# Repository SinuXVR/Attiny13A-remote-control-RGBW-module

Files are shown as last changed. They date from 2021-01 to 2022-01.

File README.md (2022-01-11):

# Attiny13A based remote control RGB module

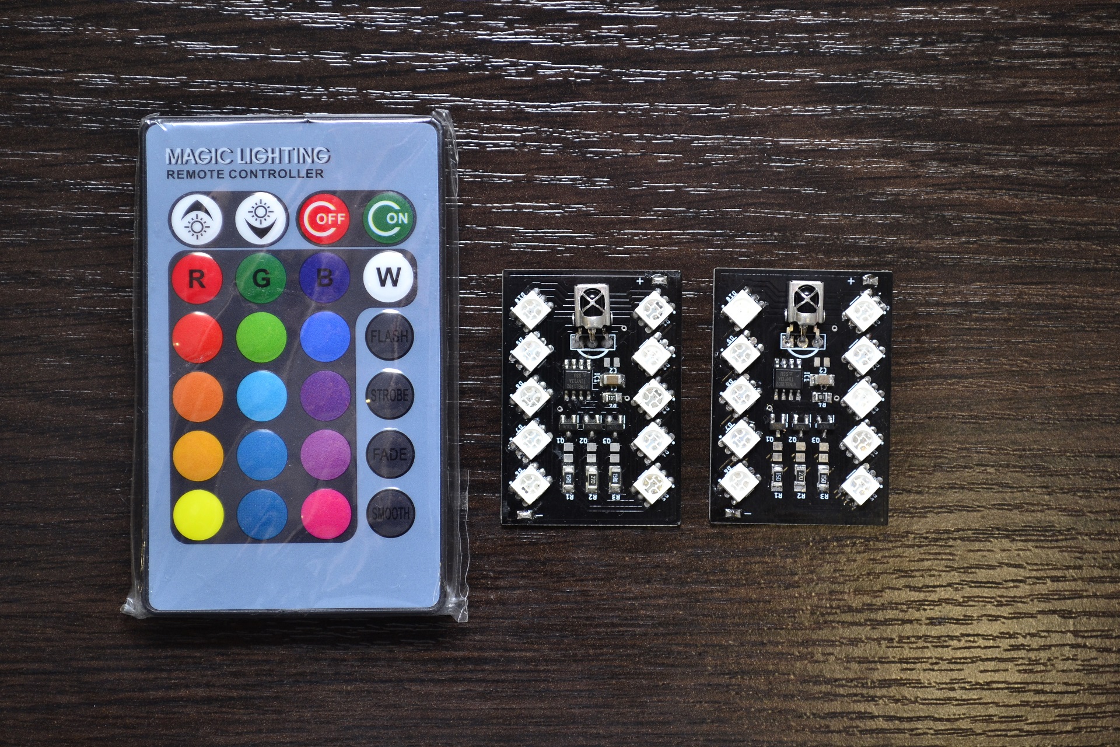
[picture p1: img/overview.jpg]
Overview


# Features

* 3 independent software PWM channel to control RGB led
* Works with cheap 24-key IR remote controller (NEC protocol)
* 16 static colors and 4 special effects
* 5 brightness levels (for static colors) and variable special effects speed
* Power ON/OFF feature
* Power consumption in OFF mode is less than 0.8mA (depends on IR receiver)
* Supply voltage: 3V to 6V (single Li-ion, 3xLR06, USB)
* Size: 868 bytes

# Remote controller

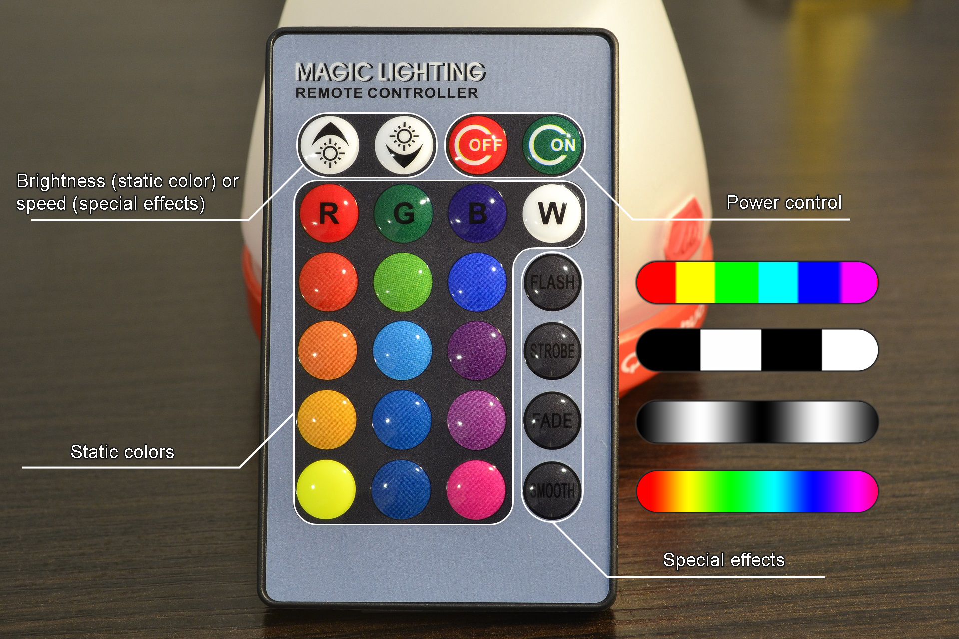
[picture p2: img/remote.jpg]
Remote keys
||
|:---:|
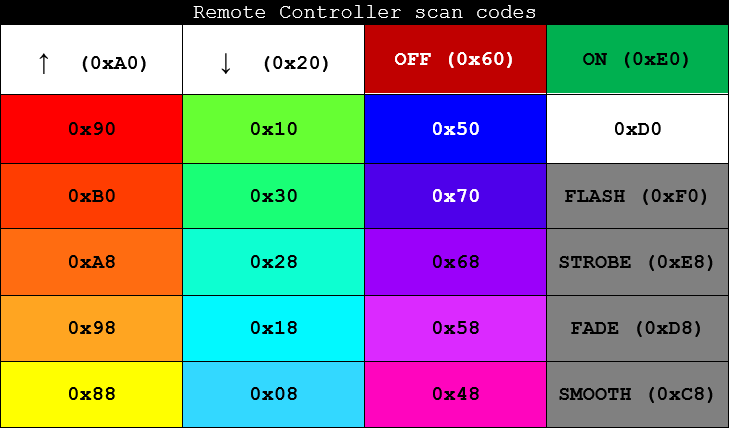
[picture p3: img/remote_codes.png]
Remote keys scan codes
||

### Showcase

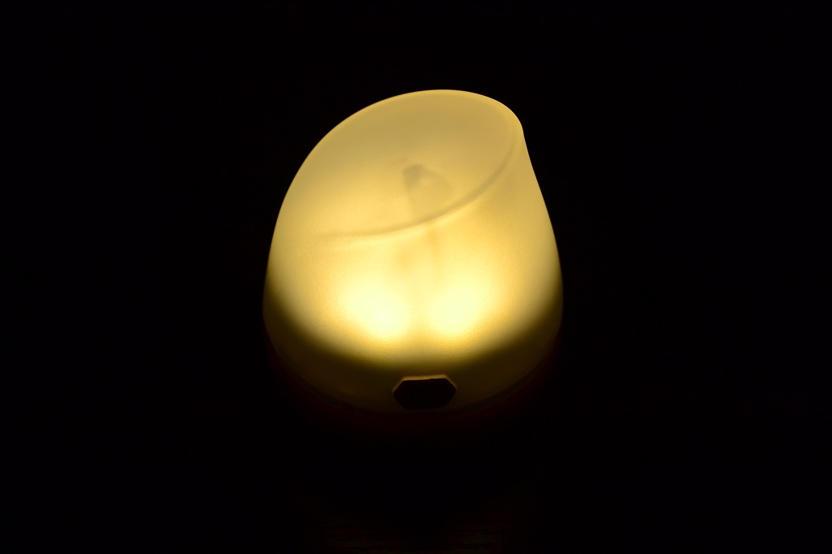
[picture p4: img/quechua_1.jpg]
White
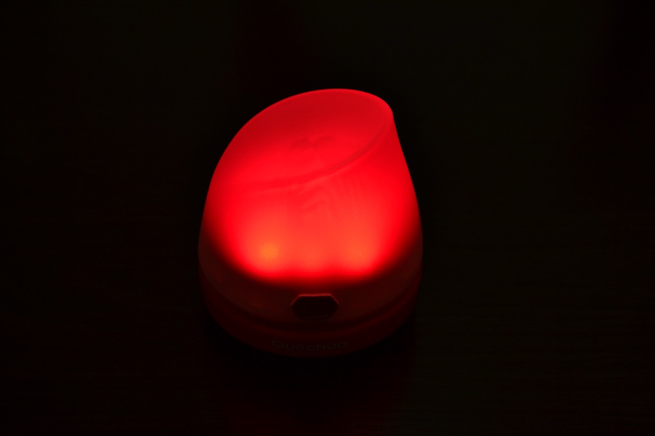
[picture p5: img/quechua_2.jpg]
Red
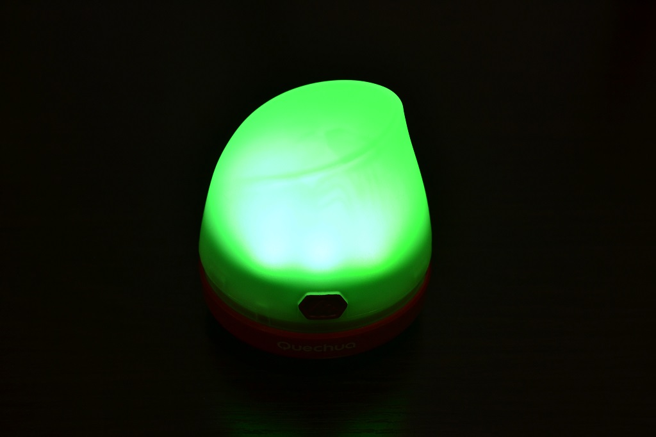
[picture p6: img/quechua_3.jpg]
Green
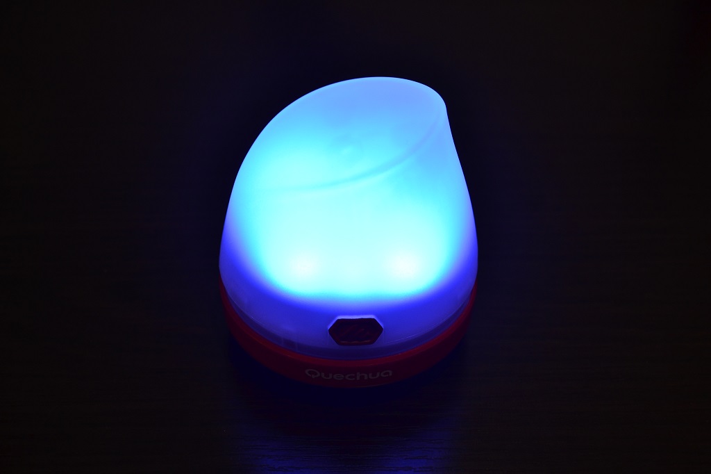
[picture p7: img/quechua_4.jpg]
Blue
|||||
|:---:|:---:|:---:|:---:|

#### Special effects

|**Flash**|**Smooth**|
|:---:|:---:|
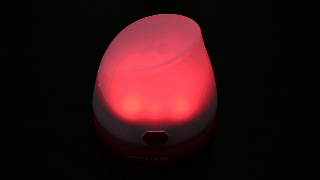
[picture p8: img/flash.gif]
Jumping
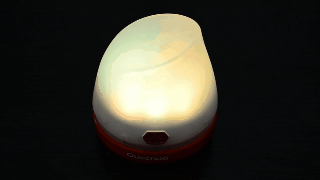
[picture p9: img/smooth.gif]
Rainbow
|||
|**Strobe**|**Fade**|
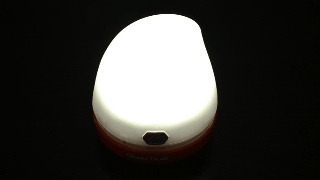
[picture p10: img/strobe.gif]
Strobe
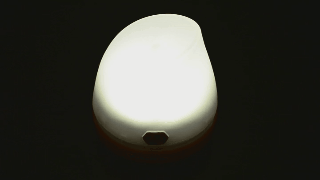
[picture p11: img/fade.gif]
Smooth fade
|||

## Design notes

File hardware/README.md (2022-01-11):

# Circuit and board

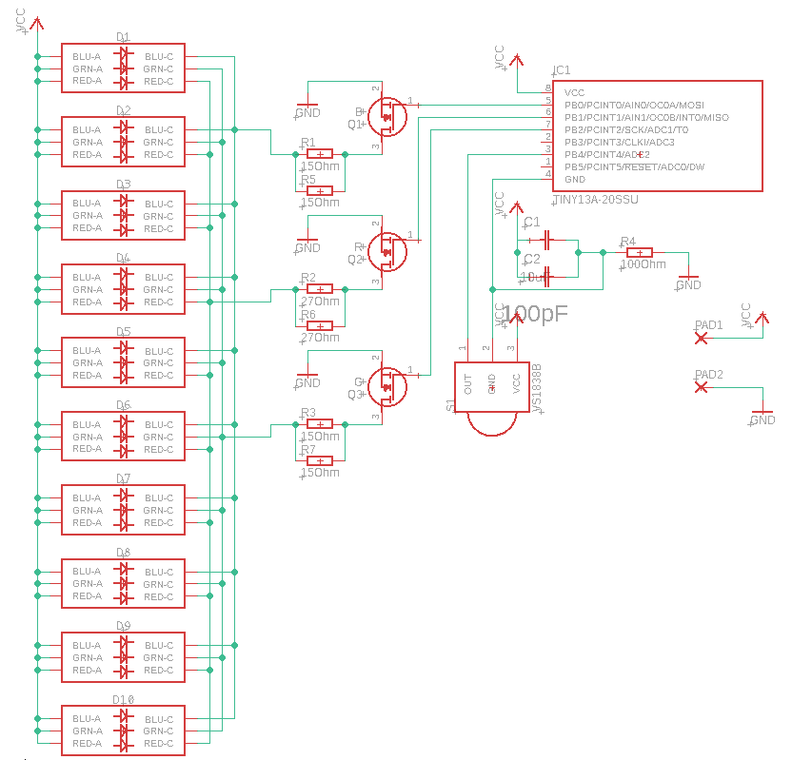
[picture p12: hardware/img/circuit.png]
Circuit diagram
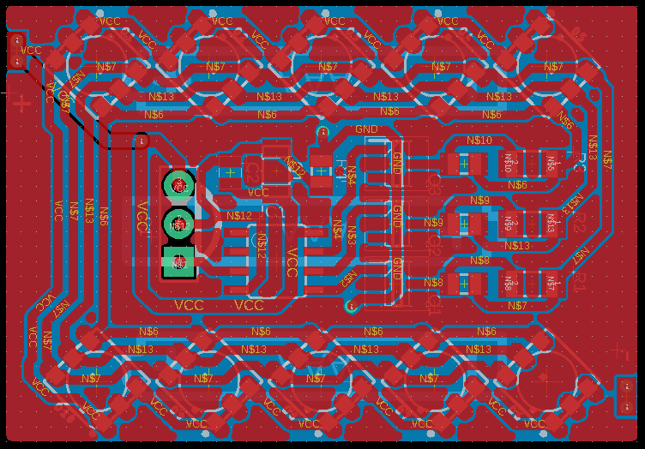
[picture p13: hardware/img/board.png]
PCB Layout
|||
|:---:|:---:|

Made in EAGLE 9.4.2

# Bill Of Materials

|**Item**|**Quantity**|**Description**|
|:---:|:---:|:---|
|D*|10|5050 RGB LED|
|Q*|3|SOT-23 N-channel MOSFET with Imax > 100mA (AO3400, IRLML2502TR)|
|R1, R3|2|15 Ohms 1206 resistor|
|R2|1|27 Ohms 1206 resistor|
|R4|1|100 Ohms 0805 resistor|
|C1|1|10pF 0805 capacitor|
|C2|1|10uF 1206 capacitor|
|U2|1|IR receiver (VS1838B, TSOP4838 or similar)|
|IC1|1|ATTINY13-20SSU|

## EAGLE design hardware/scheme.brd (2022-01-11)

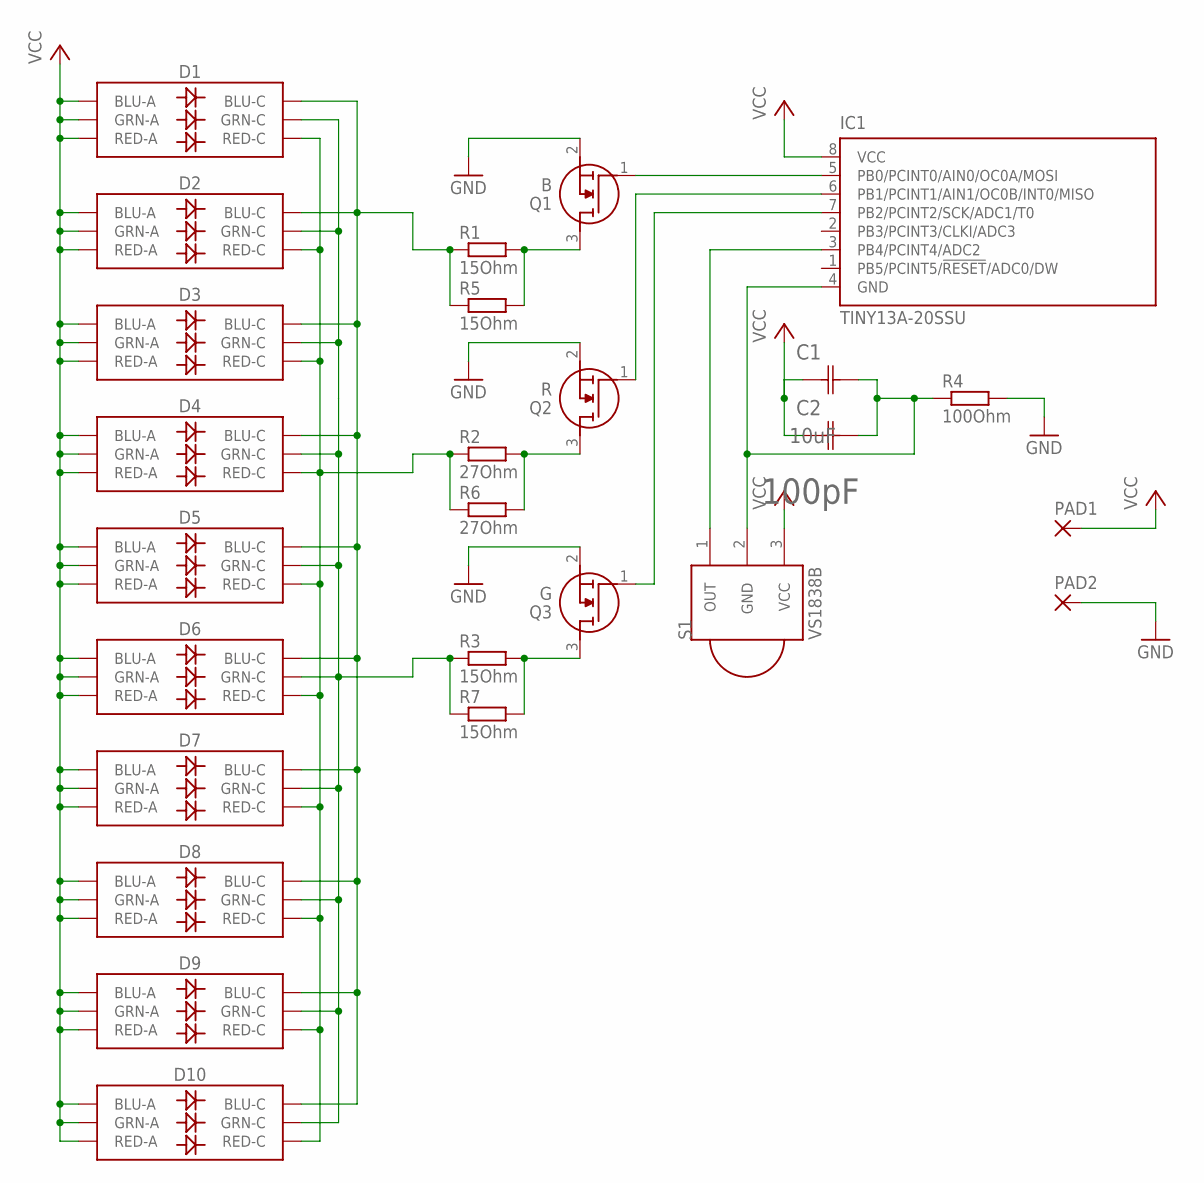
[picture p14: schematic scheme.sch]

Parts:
C1: 10uF; CAPC3216X94N
C2: 100pF; CAPC2013X94N
D1, D2, D3, D4, D5, D6, D7, D8, D9, D10: LED-RGBNO_IC; LED-TRICOLOR-5050
IC1: TINY13A-20SSU; 8S1
PAD1, PAD2: SMD2; SMD1,27-2,54
Q1: B; SOT95P280X125-3N
Q2: R; SOT95P280X125-3N
Q3: G; SOT95P280X125-3N
R1, R3: 15Ohm; R1206
R2: 27Ohm; R1206
R4: 100Ohm; R0805
R5, R7: 15Ohm; R0805
R6: 27Ohm; R0805
S1: VS1838B; PNA460XM

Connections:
GND: PAD2.1, Q1.2 (S), Q2.2 (S), Q3.2 (S), R4.2
unnamed: IC1.3 (PB4/PCINT4/ADC2), S1.1 (OUT)
unnamed: IC1.5 (PB0/PCINT0/AIN0/OC0A/MOSI), Q1.1 (G)
unnamed: IC1.6 (PB1/PCINT1/AIN1/OC0B/INT0/MISO), Q2.1 (G)
unnamed: IC1.7 (PB2/PCINT2/SCK/ADC1/T0), Q3.1 (G)
unnamed: D1.4 (GRN-C), D2.4 (GRN-C), D3.4 (GRN-C), D4.4 (GRN-C), D5.4 (GRN-C), D6.4 (GRN-C), D7.4 (GRN-C), D8.4 (GRN-C), D9.4 (GRN-C), D10.4 (GRN-C), R3.1, R7.1
unnamed: D1.6 (BLU-C), D2.6 (BLU-C), D3.6 (BLU-C), D4.6 (BLU-C), D5.6 (BLU-C), D6.6 (BLU-C), D7.6 (BLU-C), D8.6 (BLU-C), D9.6 (BLU-C), D10.6 (BLU-C), R1.1, R5.1
unnamed: Q1.3 (D), R1.2, R5.2
unnamed: Q2.3 (D), R2.2, R6.2
unnamed: Q3.3 (D), R3.2, R7.2
unnamed: C1.2 (C2), C2.2 (C2), IC1.4 (GND), R4.1, S1.2 (GND)
unnamed: D1.5 (RED-C), D2.5 (RED-C), D3.5 (RED-C), D4.5 (RED-C), D5.5 (RED-C), D6.5 (RED-C), D7.5 (RED-C), D8.5 (RED-C), D9.5 (RED-C), D10.5 (RED-C), R2.1, R6.1
VCC: C1.1 (C1), C2.1 (C1), D1.1 (BLU-A), D1.2 (RED-A), D1.3 (GRN-A), D2.1 (BLU-A), D2.2 (RED-A), D2.3 (GRN-A), D3.1 (BLU-A), D3.2 (RED-A), D3.3 (GRN-A), D4.1 (BLU-A), D4.2 (RED-A), D4.3 (GRN-A), D5.1 (BLU-A), D5.2 (RED-A), D5.3 (GRN-A), D6.1 (BLU-A), D6.2 (RED-A), D6.3 (GRN-A), D7.1 (BLU-A), D7.2 (RED-A), D7.3 (GRN-A), D8.1 (BLU-A), D8.2 (RED-A), D8.3 (GRN-A), D9.1 (BLU-A), D9.2 (RED-A), D9.3 (GRN-A), D10.1 (BLU-A), D10.2 (RED-A), D10.3 (GRN-A), IC1.8 (VCC), PAD1.1, S1.3 (VCC)

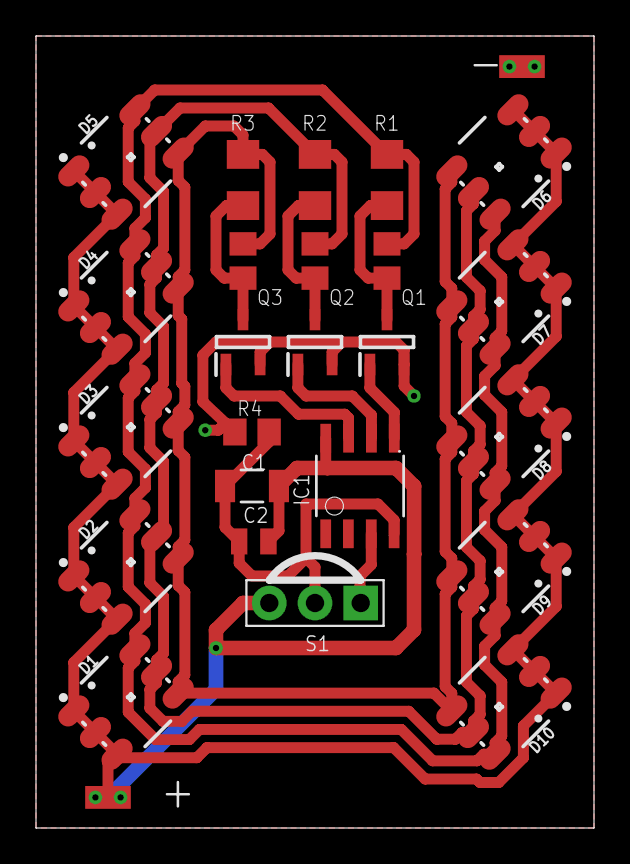
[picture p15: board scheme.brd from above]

Board: 2 copper layers, 31.0 x 44.0 mm, 26 parts (0 on the bottom side), 13 nets.

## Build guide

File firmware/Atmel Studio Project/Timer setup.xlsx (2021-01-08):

Clock, MHz | 4.8 | 16
Clock divider | 1 | 1
Timer prescaler | 256 | 1024
Actual clock, MHz | 4.8 | 16
Timer tick period, ms | 0.05333333333 | 0.064
Timer tick frequency, Hz | 18750 | 15625
Timer ticks per 1ms | 18.75 | 15.625
Ticks per 13,5ms | 253.125 | 210.9375
Ticks per 11,25ms | 210.9375 | 175.78125
Ticks per 9ms | 168.75 | 140.625
Ticks per 4,5ms | 84.375 | 70.3125
Ticks per 2,25ms | 42.1875 | 35.15625
Ticks per 1,12ms | 21 | 17.5
START_SEQ_TICKS | 169 | 141
HIGH_BIT_TICKS | 32 | 27

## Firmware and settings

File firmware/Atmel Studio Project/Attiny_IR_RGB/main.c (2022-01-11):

/**
 * Chip type: Attiny13
 * Clock frequency: 4.8MHz without divider
 * Flash command: avrdude -p t13 -c avrisp -b 19200 -u -Uflash:w:Attiny_IR_RGB.hex:a -Ulfuse:w:0x71:m -Uhfuse:w:0xFF:m
 *                       +--------+
 *        [        (PB5) |1*     8| (VCC)  Power ]
 *        [        (PB3) |2      7| (PB2)   BLUE ]
 *        [ VS1838 (PB4) |3      6| (PB1)  GREEN ]
 *        [ Ground (GND) |4      5| (PB0)    RED ]
 *                       +--------+
 */

#define F_CPU 4800000UL
#include <avr/io.h>
#include "lib/common.h"
#include "lib/ir.h"
#include "lib/led_pwm.h"
#include "lib/animation.h"

// Entry point
int main(void) {
	// Set up
	power_off_init();
	pwm_init_rgb();
	ir_init();
	
	// Initial state - STATE_COLOR with power off bit
	byte current_state = STATE_COLOR | 0x80;
	
	// Animation and brightness parameters
	byte anim_rate = ANIM_RATE_INITIAL_VALUE;
	byte anim_counter = 0;
	byte anim_local_counter = 0;
	byte brightness = BRIGHTNESS_INITIAL_VALUE;
	
	// Main loop
	while(1) {
		// Check if new command was received and change state
		if (ir_has_new_command()) {
			byte command = ir_get_received_command();

			// Power on and power off
			if (command == IR_KEY_POWER_ON) {
				clear_power_off_bit(current_state);
				continue;
			}
			if (command == IR_KEY_POWER_OFF) {
				set_power_off_bit(current_state);
				continue;
			}
			
			// Ignore other commands during sleep
			if (has_power_off_bit(current_state)) continue;
			
			// Change brightness or animation speed depending on current mode
			if (command == IR_KEY_UP) {
				if (current_state == STATE_COLOR) {
					brightness = anim_inc_brightness(brightness);
				}
				else {
					anim_rate = anim_dec_rate(anim_rate);
				}
				continue;
			}
			if (command == IR_KEY_DOWN) {
				if (current_state == STATE_COLOR) {
					brightness = anim_dec_brightness(brightness);
				}
				else {
					anim_rate = anim_inc_rate(anim_rate);
				}
				continue;
			}
			
			// Change animation modes
			if (command == IR_KEY_ANIM_RAINBOW) {
				current_state = STATE_RAINBOW_ANIMATION;
				continue;
			}
			if (command == IR_KEY_ANIM_JUMP) {
				current_state = STATE_JUMP_ANIMATION;
				continue;
			}
			if (command == IR_KEY_ANIM_FADE) {
				current_state = STATE_FADE_ANIMATION;
				continue;
			}
			if (command == IR_KEY_ANIM_STROBE) {
				current_state = STATE_STROBE_ANIMATION;
				// For some reason this continue increases code size
				// continue;
			}
			
			// Otherwise try to set color value
			if (anim_set_color_by_key(command)) {
				current_state = STATE_COLOR;
				anim_set_brightness(brightness);
			}
		}
		
		// If IR_KEY_POWER_OFF has been pressed - disable all outputs and go to sleep
		if (has_power_off_bit(current_state)) {
			if (ir_is_idle_state()) power_off();
			continue;
		}
		
		// Calculate animation step
		if (++anim_counter >= anim_rate) {
			if (current_state == STATE_JUMP_ANIMATION) anim_jump(anim_local_counter); else
			if (current_state == STATE_FADE_ANIMATION) anim_fade(anim_local_counter); else
			if (current_state == STATE_STROBE_ANIMATION) anim_strobe(anim_local_counter); else
			if (current_state == STATE_RAINBOW_ANIMATION) anim_rainbow();
			anim_local_counter++;
			anim_counter = 0;
		}
		
		// Do PWM
		pwm_rgb(r_current_value, g_current_value, b_current_value);

	}
	
	return 0;
}

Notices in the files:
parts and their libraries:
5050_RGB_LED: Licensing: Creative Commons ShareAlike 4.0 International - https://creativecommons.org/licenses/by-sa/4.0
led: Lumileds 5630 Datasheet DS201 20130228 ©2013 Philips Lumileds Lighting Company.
